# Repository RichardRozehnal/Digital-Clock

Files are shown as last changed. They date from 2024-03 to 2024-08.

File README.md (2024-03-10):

# Digital Clock

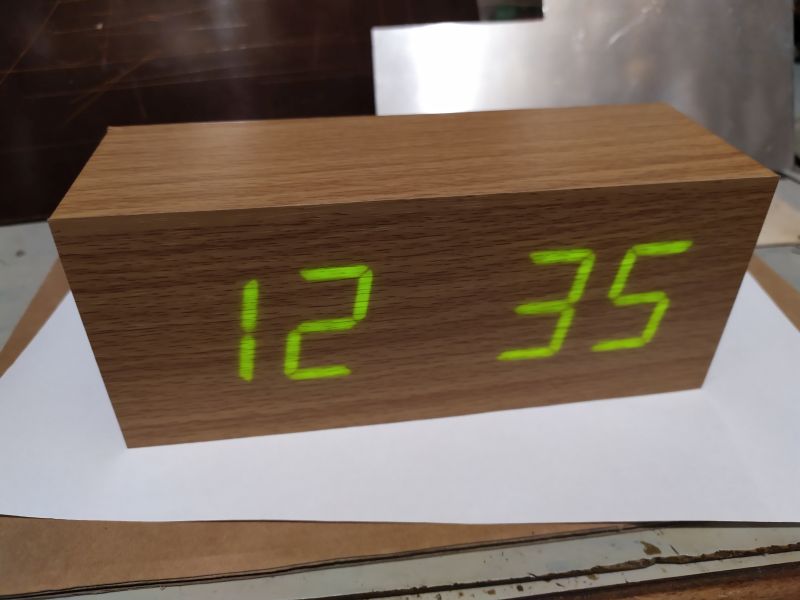
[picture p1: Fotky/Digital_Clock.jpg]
Digital Clock


Jednoduché digitální hodiny ze čtyř 7mi segmentových displejů.

#### Funkce tlačítek (z boku):
1. tlačítko - zapne nastavování hodin
2. tlačítko - přepíná hodiny nebo minuty nahoru
3. tlačítko - přepíná hodiny nebo minuty dolů

## Další fotky

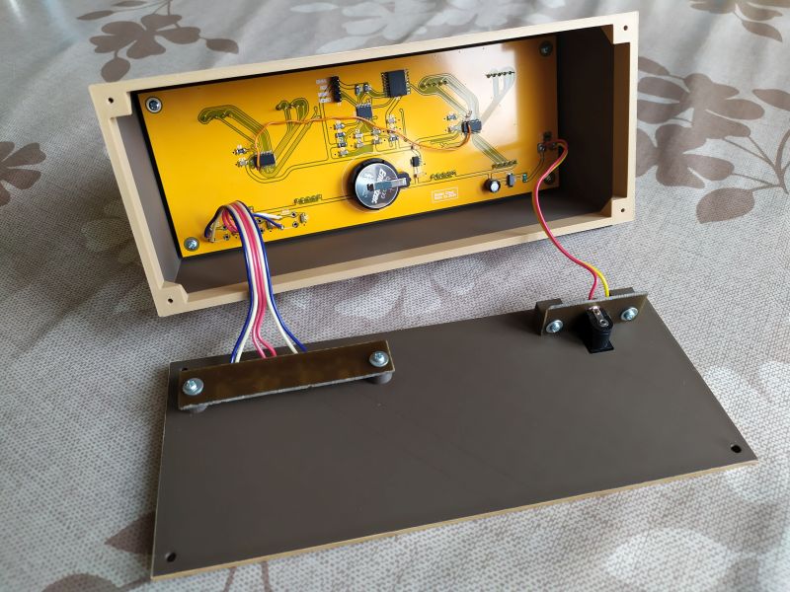
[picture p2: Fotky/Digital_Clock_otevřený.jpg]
Digital Clock otevřený

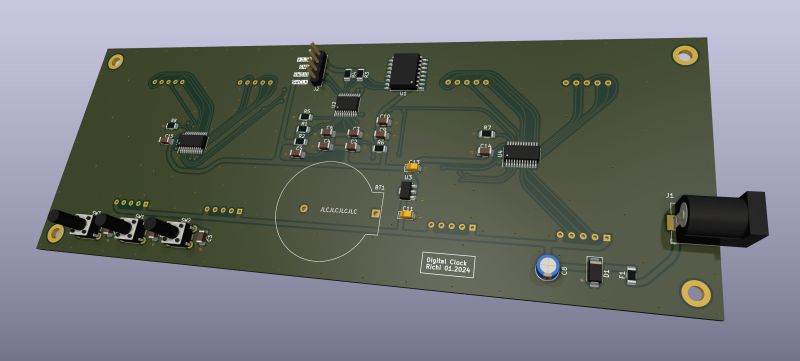
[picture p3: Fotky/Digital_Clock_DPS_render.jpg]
Digital Clock DPS render

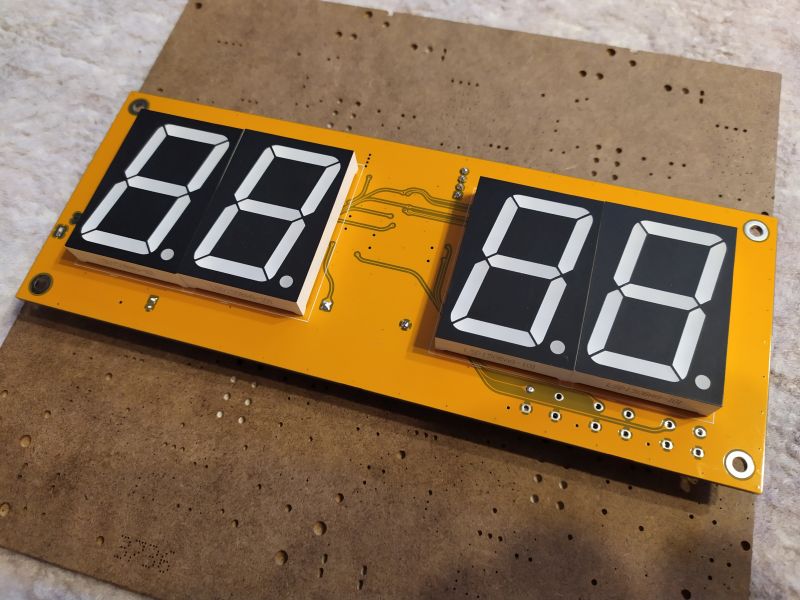
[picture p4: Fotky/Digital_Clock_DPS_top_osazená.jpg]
Digital Clock DPS top osazená

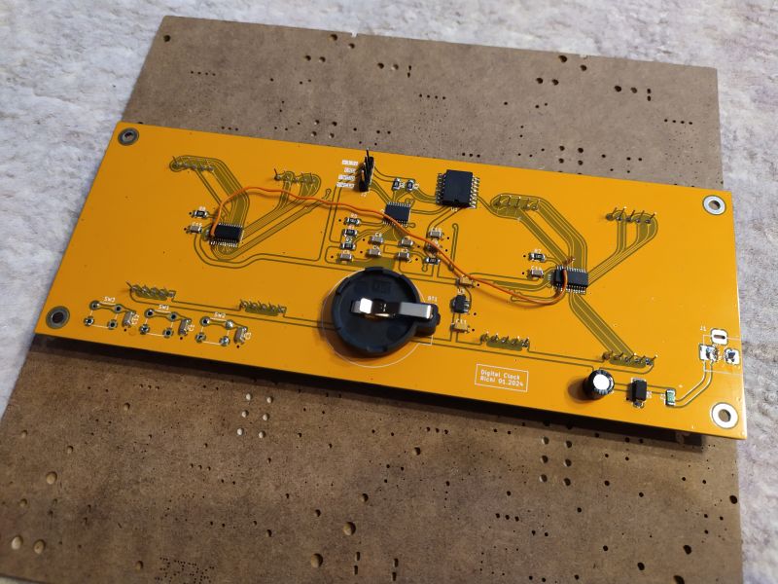
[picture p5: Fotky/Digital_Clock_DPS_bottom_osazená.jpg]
Digital Clock DPS bottom osazená


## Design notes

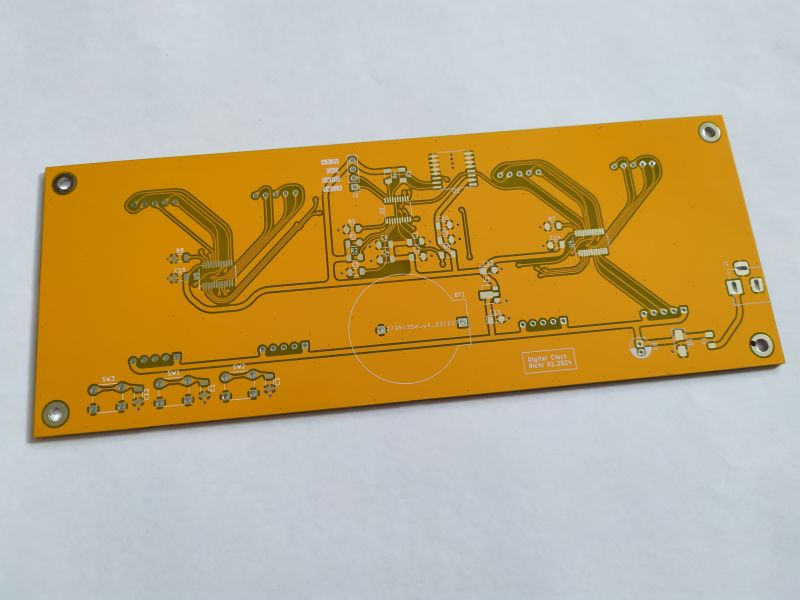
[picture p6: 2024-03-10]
Fotky/Digital_Clock_DPS_top.jpg

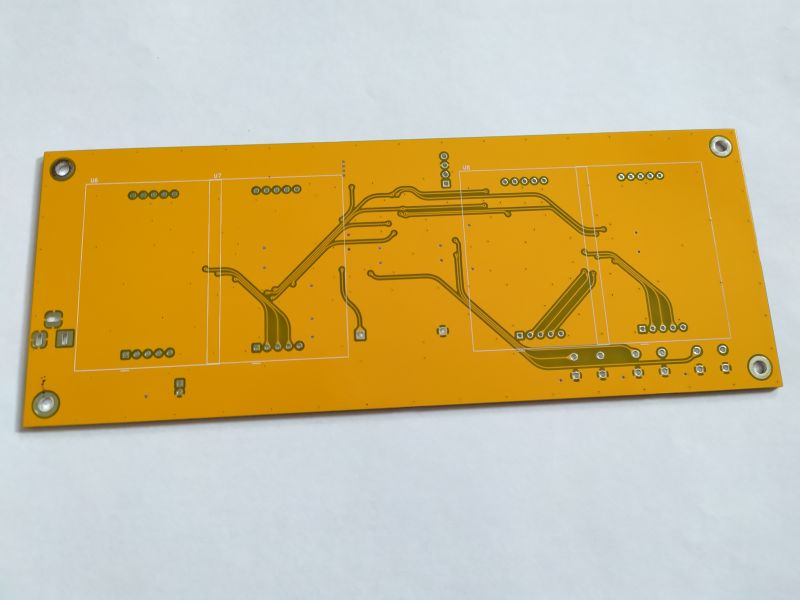
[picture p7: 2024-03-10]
Fotky/Digital_Clock_DPS_bottom.jpg

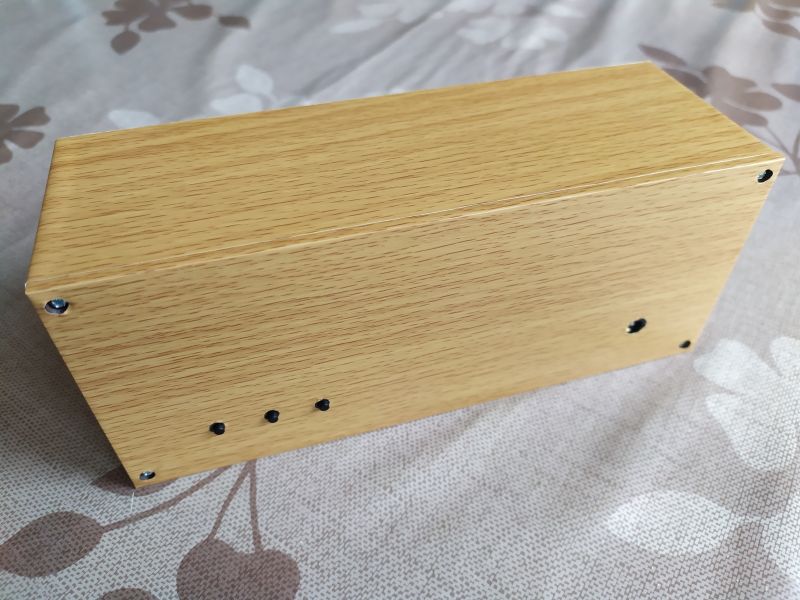
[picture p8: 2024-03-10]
Fotky/Digital_Clock_zadek.jpg

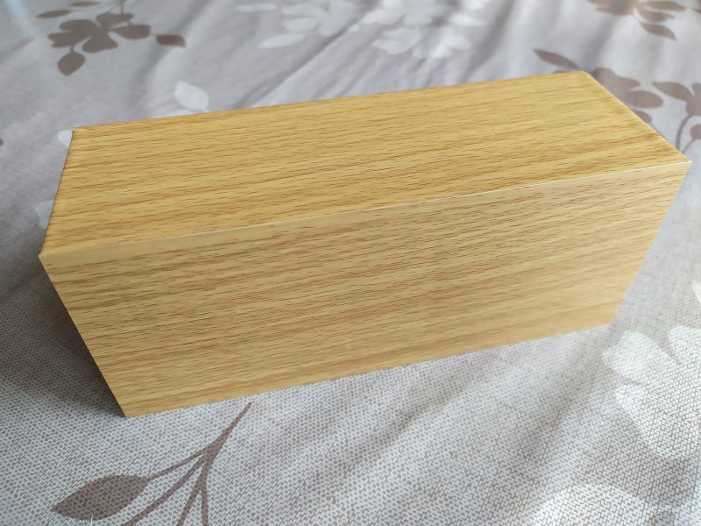
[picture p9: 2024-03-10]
Fotky/Digital_Clock_předek.jpg

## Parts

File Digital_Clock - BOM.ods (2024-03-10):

Digital Clock – BOM
Ref | Qnty | Value | Cmp name | Footprint | Description
BT1 | 1 | 3V CR2032 | Battery_Cell | Digital_Clock:BatteryHolder_ComfortableElectronic_CH273-2450_1x2450 | Single-cell battery
C1, C3, C5, C6, C7, C10, C12, C14, C15 | 9 | 100nF | C | Digital_Clock:C_1206_3216Metric | Unpolarized capacitor
C2 | 1 | 10uF | C | Digital_Clock:C_1206_3216Metric | Unpolarized capacitor
C4, C9 | 2 | 1uF | C | Digital_Clock:C_1206_3216Metric | Unpolarized capacitor
C8 | 1 | 100uF/10V | C_Polarized | Digital_Clock:CP_Radial_D5.0mm_P2.00mm | Polarized capacitor
C11, C13 | 2 | 10uF/16V | C_Polarized | Digital_Clock:CP_EIA-3216-18_Kemet-A | Polarized capacitor
D1 | 1 | P4SMAJ5.0A | SMAJ5.0A | Digital_Clock:D_SMA | 400W unidirectional Transient Voltage Suppressor, 5.0Vr, SMA(DO-214AC)
F1 | 1 | SN050-08 | Polyfuse | Digital_Clock:Fuse_1206_3216Metric | Resettable fuse, polymeric positive temperature coefficient
J1 | 1 | Barrel_Jack_Switch | Barrel_Jack_Switch | Digital_Clock:BarrelJack_Horizontal | DC Barrel Jack with an internal switch
J2 | 1 | Programming Connector | Conn_01x04 | Digital_Clock:PinHeader_1x04_P2.54mm_Vertical | Generic connector, single row, 01x04, script generated (kicad-library-utils/schlib/autogen/connector/)
R1, R2, R6 | 3 | 20K | R | Digital_Clock:R_1206_3216Metric | Resistor
R3, R4, R5 | 3 | 10K | R | Digital_Clock:R_1206_3216Metric | Resistor
R7, R8 | 2 | 3K3 | R | Digital_Clock:R_1206_3216Metric | Resistor
SW1 | 1 | Up | SW_Push | Digital_Clock:SW_PUSH_6mm_H13mm | Push button switch, generic, two pins
SW2 | 1 | Down | SW_Push | Digital_Clock:SW_PUSH_6mm_H13mm | Push button switch, generic, two pins
SW3 | 1 | Set | SW_Push | Digital_Clock:SW_PUSH_6mm_H13mm | Push button switch, generic, two pins
U1 | 1 | DS3231M | DS3231M | Digital_Clock:SOIC-16W_7.5x10.3mm_P1.27mm | Extremely Accurate I2C-Integrated RTC/TCXO/Crystal SOIC-16
U2 | 1 | STM32L031F6Px | STM32L031F6Px | Digital_Clock:TSSOP-20_4.4x6.5mm_P0.65mm | STMicroelectronics Arm Cortex-M0+ MCU, 32KB flash, 8KB RAM, 32 MHz, 1.8-3.6V, 16 GPIO, TSSOP20
U3 | 1 | HT7533-1 | HT75xx-1-SOT89 | Digital_Clock:SOT-89-3 | 100mA Low Dropout Voltage Regulator, Fixed Output, SOT89
U4, U5 | 2 | TLC59283DBQR | TLC59283DBQR | Digital_Clock:QSOP-24_3.9x8.7mm_P0.635mm | 16-channel LED driver
U6, U7, U8, U9 | 4 | LSD150BAG-101 | LSD150BAG-101 | Digital_Clock:LSD150BAG-101 | Green Single-digit Numeric Display with white white diffused lens, common anode

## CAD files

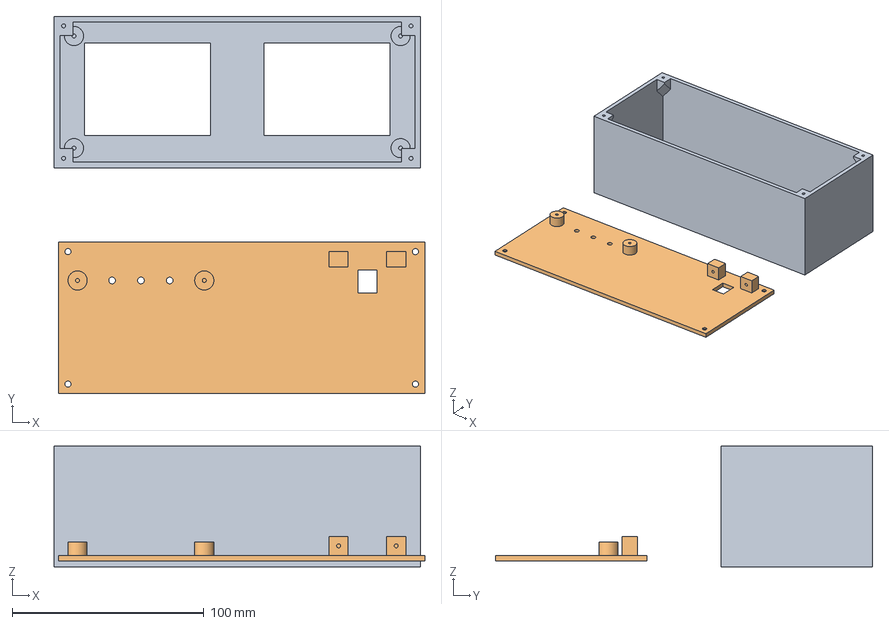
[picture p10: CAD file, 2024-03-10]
Krabička/Digital Clock Enclosure v22.step
193.3 x 196.6 x 63.0 mm

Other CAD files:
Krabička/Digital Clock Enclosure v22.3mf
Krabička/Digital Clock Enclosure v22.f3d
Krabička/Digital Clock Enclosure v22.stl

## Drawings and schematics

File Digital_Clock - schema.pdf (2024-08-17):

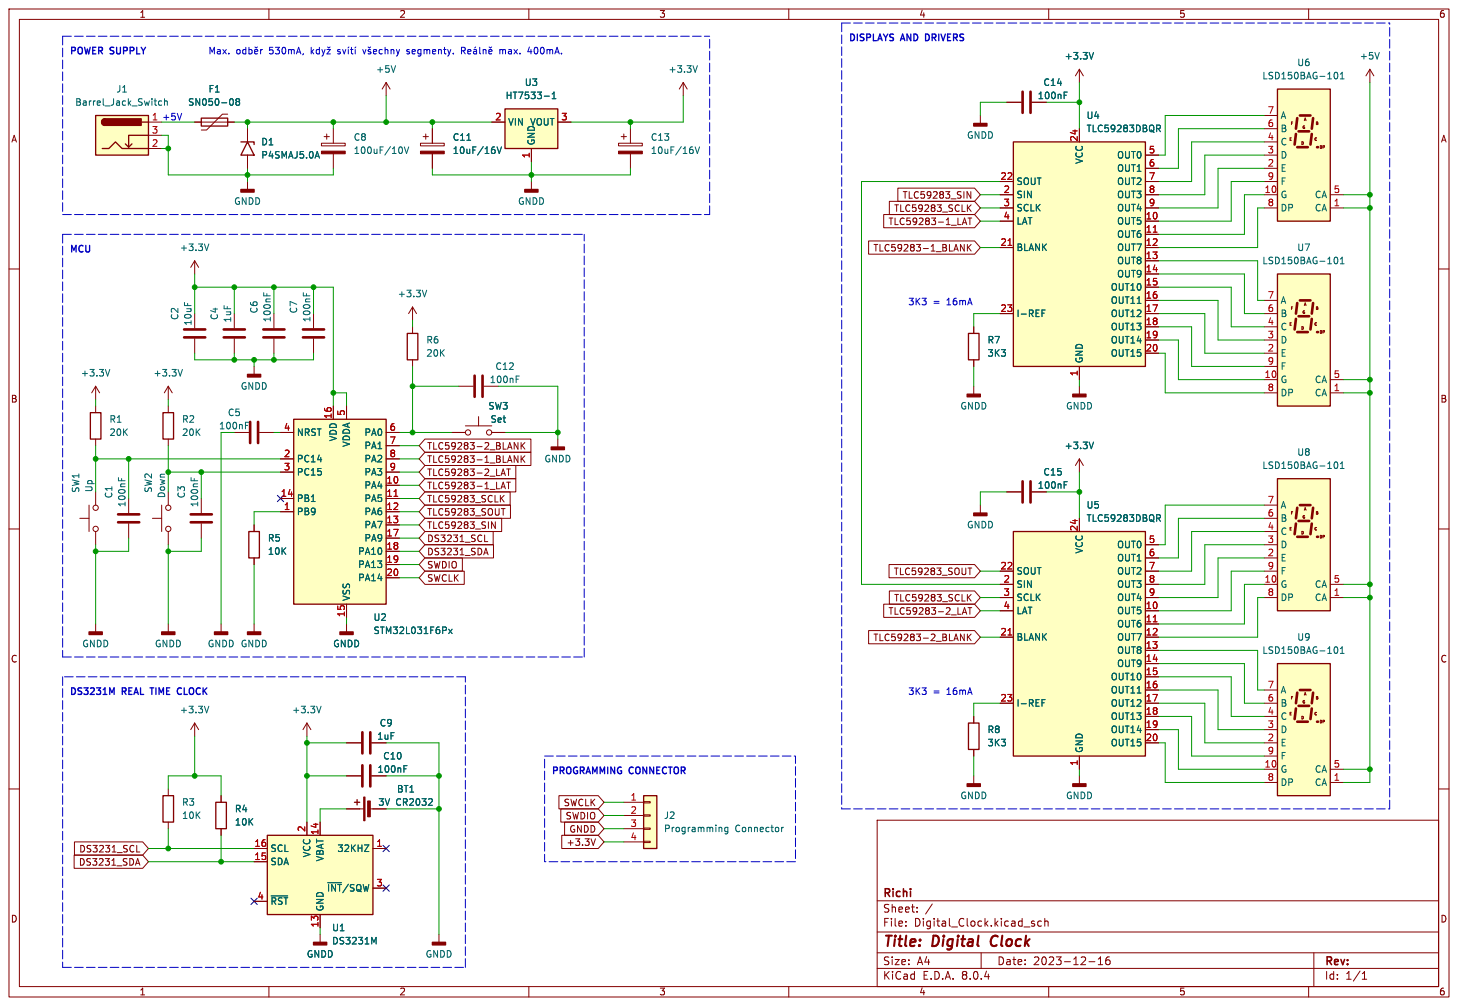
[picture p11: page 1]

DISPLAYS AND DRIVERS MCU

File: Digital_Clock.kicad_sch Sheet: / Richi GNDD

Id: 1/1 Title: Digital Clock

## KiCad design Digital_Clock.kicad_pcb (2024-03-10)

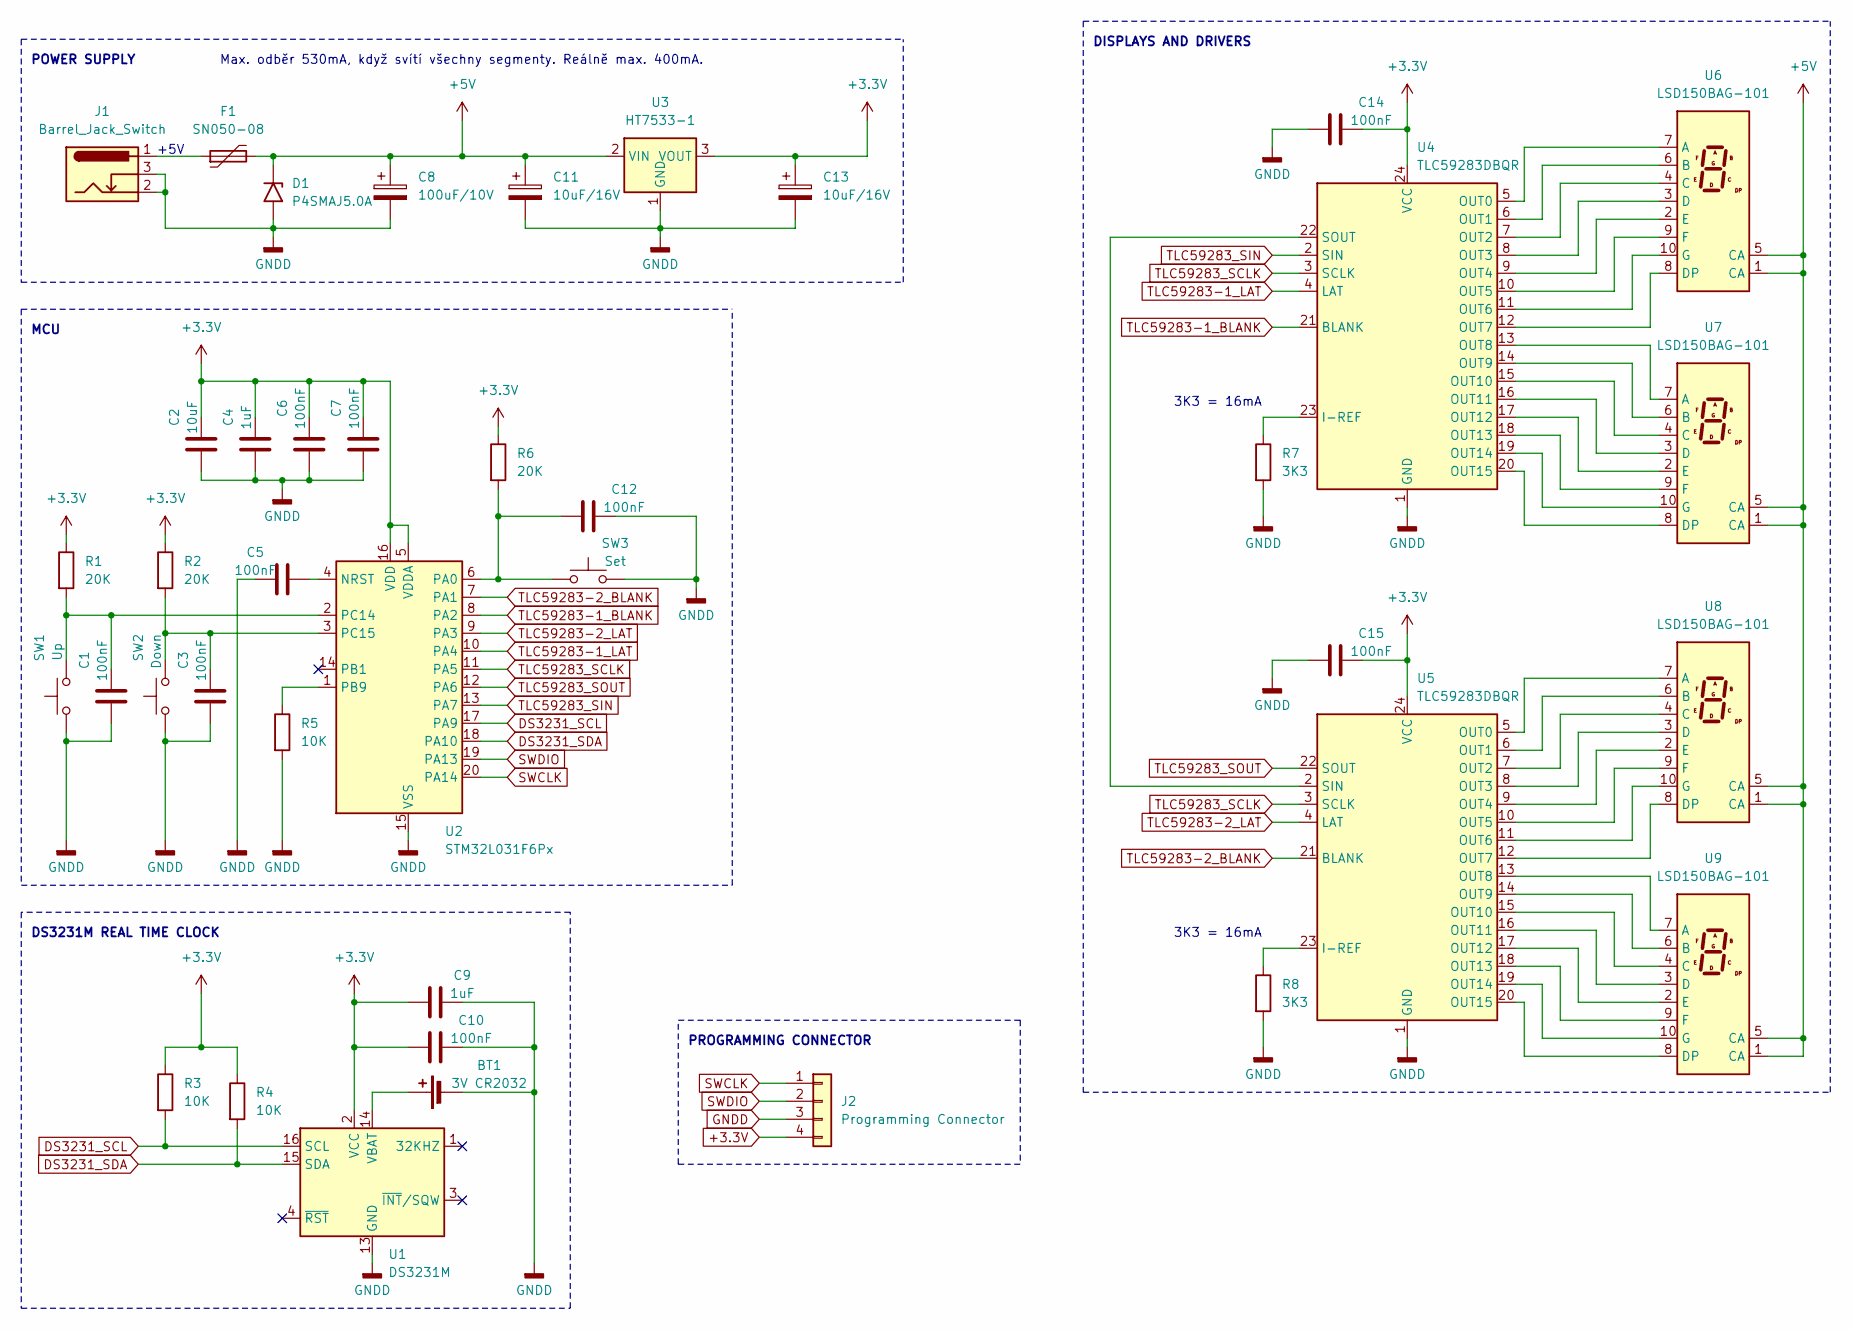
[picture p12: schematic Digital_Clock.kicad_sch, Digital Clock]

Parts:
BT1: 3V CR2032; BatteryHolder_ComfortableElectronic_CH273-2450_1x2450
C1, C3, C5, C6, C7, C10, C12, C14, C15: 100nF; C_1206_3216Metric
C2: 10uF; C_1206_3216Metric
C4, C9: 1uF; C_1206_3216Metric
C8: 100uF/10V; CP_Radial_D5.0mm_P2.00mm
C11, C13: 10uF/16V; CP_EIA-3216-18_Kemet-A
D1: P4SMAJ5.0A; D_SMA
F1: SN050-08; Fuse_1206_3216Metric
J1: Barrel_Jack_Switch; BarrelJack_Horizontal
J2: Programming Connector; PinHeader_1x04_P2.54mm_Vertical
R1, R2, R6: 20K; R_1206_3216Metric
R3, R4, R5: 10K; R_1206_3216Metric
R7, R8: 3K3; R_1206_3216Metric
SW1: Up; SW_PUSH_6mm_H13mm
SW2: Down; SW_PUSH_6mm_H13mm
SW3: Set; SW_PUSH_6mm_H13mm
U1: DS3231M; SOIC-16W_7.5x10.3mm_P1.27mm
U2: STM32L031F6Px; TSSOP-20_4.4x6.5mm_P0.65mm
U3: HT7533-1; SOT-89-3
U4, U5: TLC59283DBQR; QSOP-24_3.9x8.7mm_P0.635mm
U6, U7, U8, U9: LSD150BAG-101

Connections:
+3.3V: C2.2, C4.2, C6.2, C7.2, C9.1, C10.1, C13.1, C14.2, C15.2, J2.4, R1.1, R2.1, R3.1, R4.1, R6.1, U1.2 (VCC), U2.5 (VDDA), U2.16 (VDD), U3.3 (VOUT), U4.24 (VCC), U5.24 (VCC)
+5V: C8.1, C11.1, D1.1 (A1), F1.2, U3.2 (VIN), U6.1 (CA), U6.5 (CA), U7.1 (CA), U7.5 (CA), U8.1 (CA), U8.5 (CA), U9.1 (CA), U9.5 (CA)
DS3231_SCL: R3.2, U1.16 (SCL), U2.17 (PA9)
DS3231_SDA: R4.2, U1.15 (SDA), U2.18 (PA10)
GNDD: BT1.2 (-), C1.1, C2.1, C3.1, C4.1, C5.1, C6.1, C7.1, C8.2, C9.2, C10.2, C11.2, C12.2, C13.2, C14.1, C15.1, D1.2 (A2), J1.2, J1.3, J2.3, R5.2, R7.2, R8.2, SW1.1, SW2.1, SW3.2, U1.5 (GND), U1.6 (GND), U1.7 (GND), U1.8 (GND), U1.9 (GND), U1.10 (GND), U1.11 (GND), U1.12 (GND), U1.13 (GND), U2.15 (VSS), U3.1 (GND), U4.1 (GND), U5.1 (GND)
unnamed: BT1.1 (+), U1.14 (VBAT)
unnamed: F1.1, J1.1
unnamed: C5.2, U2.4 (NRST)
unnamed: C12.1, R6.2, SW3.1, U2.6 (PA0)
unnamed: R5.1, U2.1 (PB9)
unnamed: C1.2, R1.2, SW1.2, U2.2 (PC14)
unnamed: C3.2, R2.2, SW2.2, U2.3 (PC15)
unnamed: R7.1, U4.23 (I-REF)
unnamed: U4.5 (OUT0), U6.7 (A)
unnamed: U4.6 (OUT1), U6.6 (B)
unnamed: U4.7 (OUT2), U6.4 (C)
unnamed: U4.8 (OUT3), U6.3 (D)
unnamed: U4.9 (OUT4), U6.2 (E)
unnamed: U4.10 (OUT5), U6.9 (F)
unnamed: U4.11 (OUT6), U6.10 (G)
unnamed: U4.12 (OUT7), U6.8 (DP)
unnamed: U4.13 (OUT8), U7.7 (A)
unnamed: U4.14 (OUT9), U7.6 (B)
unnamed: U4.15 (OUT10), U7.4 (C)
unnamed: U4.16 (OUT11), U7.3 (D)
unnamed: U4.17 (OUT12), U7.2 (E)
unnamed: U4.18 (OUT13), U7.9 (F)
unnamed: U4.19 (OUT14), U7.10 (G)
unnamed: U4.20 (OUT15), U7.8 (DP)
unnamed: U4.22 (SOUT), U5.2 (SIN)
unnamed: R8.1, U5.23 (I-REF)
unnamed: U5.5 (OUT0), U8.7 (A)
unnamed: U5.6 (OUT1), U8.6 (B)
unnamed: U5.7 (OUT2), U8.4 (C)
unnamed: U5.8 (OUT3), U8.3 (D)
unnamed: U5.9 (OUT4), U8.2 (E)
unnamed: U5.10 (OUT5), U8.9 (F)
unnamed: U5.11 (OUT6), U8.10 (G)
unnamed: U5.12 (OUT7), U8.8 (DP)
unnamed: U5.13 (OUT8), U9.7 (A)
unnamed: U5.14 (OUT9), U9.6 (B)
unnamed: U5.15 (OUT10), U9.4 (C)
unnamed: U5.16 (OUT11), U9.3 (D)
unnamed: U5.17 (OUT12), U9.2 (E)
unnamed: U5.18 (OUT13), U9.9 (F)
unnamed: U5.19 (OUT14), U9.10 (G)
unnamed: U5.20 (OUT15), U9.8 (DP)
SWCLK: J2.1, U2.20 (PA14)
SWDIO: J2.2, U2.19 (PA13)
TLC59283-1_BLANK: U2.8 (PA2), U4.21 (BLANK)
TLC59283-1_LAT: U2.10 (PA4), U4.4 (LAT)
TLC59283-2_BLANK: U2.7 (PA1), U5.21 (BLANK)
TLC59283-2_LAT: U2.9 (PA3), U5.4 (LAT)
TLC59283_SCLK: U2.11 (PA5), U4.3 (SCLK), U5.3 (SCLK)
TLC59283_SIN: U2.13 (PA7), U4.2 (SIN)
TLC59283_SOUT: U2.12 (PA6), U5.22 (SOUT)

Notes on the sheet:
3K3 = 16mA
POWER SUPPLY
DS3231M REAL TIME CLOCK
MCU
+5V
Max. odběr 530mA, když svítí všechny segmenty. Reálně max. 400mA.
DISPLAYS AND DRIVERS
PROGRAMMING CONNECTOR

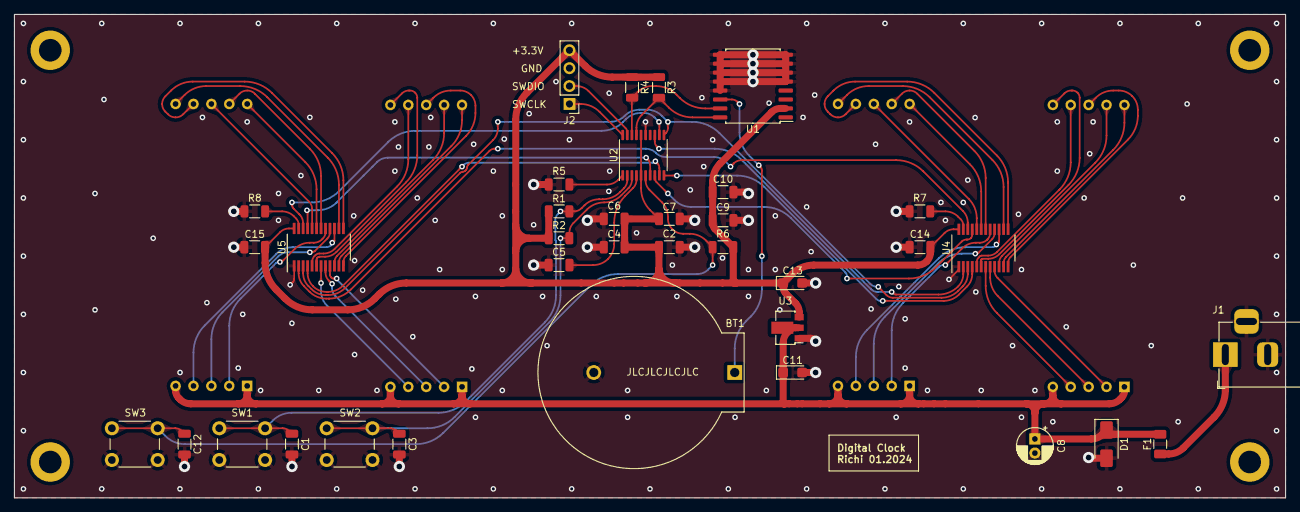
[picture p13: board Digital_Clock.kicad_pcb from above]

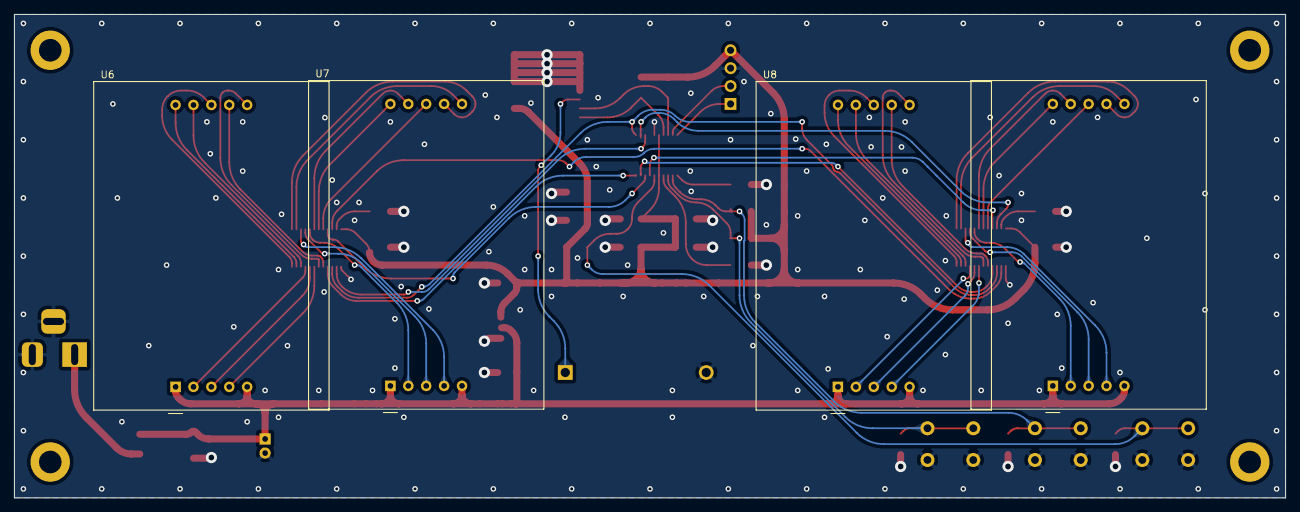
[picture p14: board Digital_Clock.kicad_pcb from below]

Board: 2 copper layers, 180.3 x 68.6 mm, 40 parts (4 on the bottom side), 56 nets.
